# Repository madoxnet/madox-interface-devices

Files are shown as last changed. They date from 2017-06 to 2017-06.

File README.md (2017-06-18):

Madox-Ergonomic-Trackball
Mouse-Ergonomics-Test

|Function|Component|Module|
|---|---|---|
|Processing|ARM Cortex M4F|Adafruit Feather nRF52 Bluefruit LE |
|Power source|1000 mAh Lithium Polymer||
|Optical Sensing|Avago ADNS-9800||
|Optical Lens|Avago ADNS-6190-002||

## Design Parameters
|Parameter|Min|Nom|Max|
|---|---|---|---|
|Sensing distance|2.18mm|2.4mm|2.62|
|Bearing diameter||3mm||
|Trackball diameter||40mm||
|Handedness||Right||

## Controls
- Left Mouse Button
- Right Mouse Button
- Scroll Wheel
- Scroll Wheel Centre Mouse
- Power Switch
- ~~Scroll Wheel left right = Ctrl Tab / Ctrl Shift Tab?~~

## Target Specifications
|Parameter|Min|
|---|---|
|Ball diameter|40mm|
|Ball Material|Tiger's Eye|
|Ball Suspension|3mm Silicon Nitride (Si<sub>3</sub>N<sub>4</sub>) Round Bearings in Polycprolactone casing |
|Construction|Acrylonitrile butadiene styrene|
|Tracking Technology|Laser Optical Sensing|
|Tracking Resolution|Up to 8200 counts per inch|
|Tracking Speed|Up to 150 inches per second|

<https://en.wikipedia.org/wiki/Tiger%27s_eye>
<https://en.wikipedia.org/wiki/Silicon_nitride>

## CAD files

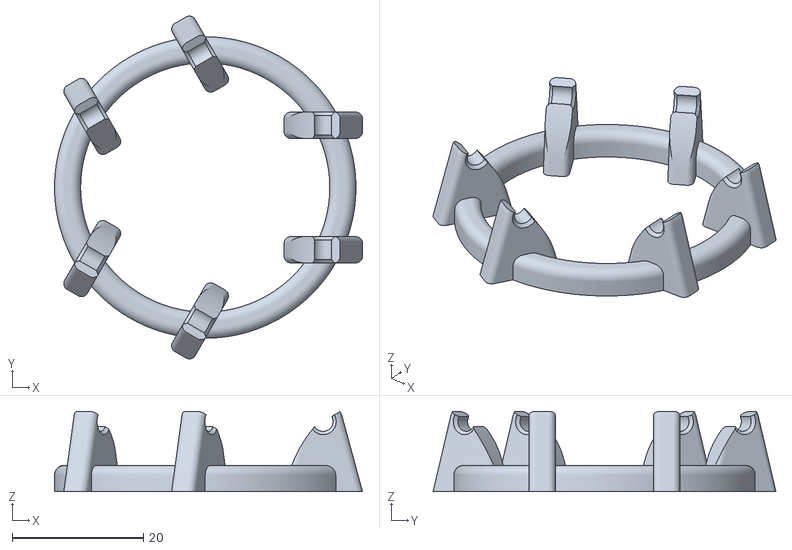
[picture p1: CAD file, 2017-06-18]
hw/test/TrackballTest-Roller.stl
47.0 x 52.3 x 12.2

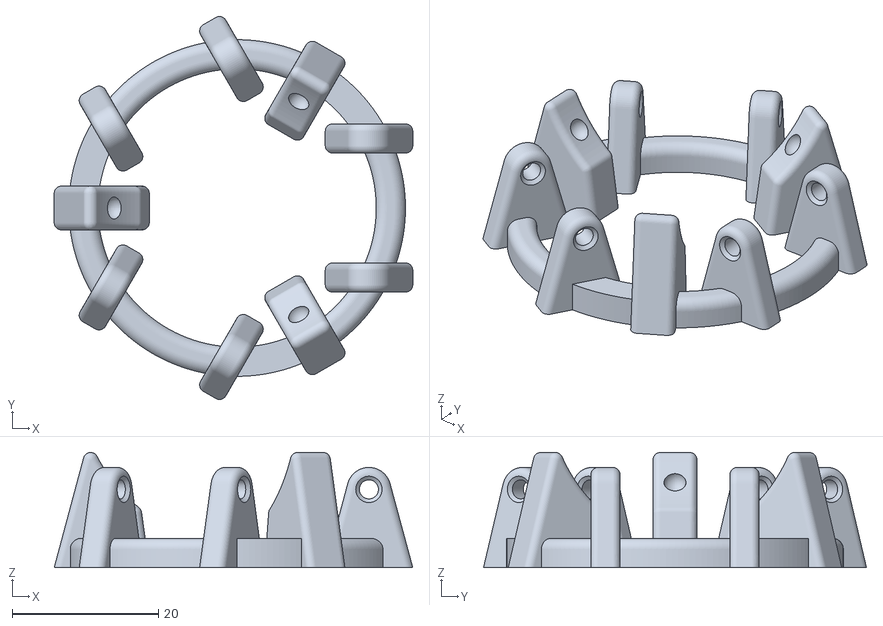
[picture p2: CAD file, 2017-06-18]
hw/test/TrackballTest-Frankenstein.stl
49.0 x 52.3 x 15.7

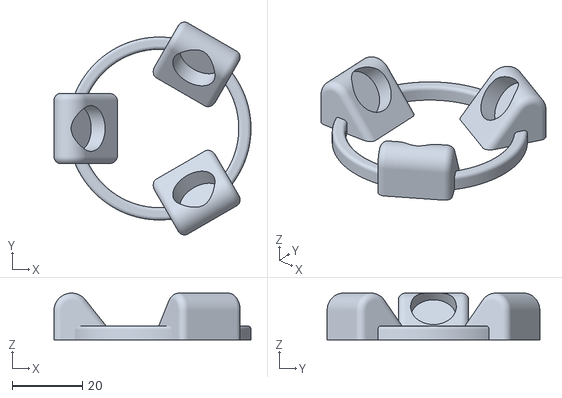
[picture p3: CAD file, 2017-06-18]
hw/test/TrackballTest-BallTransferUnit.stl
56.0 x 60.5 x 13.3

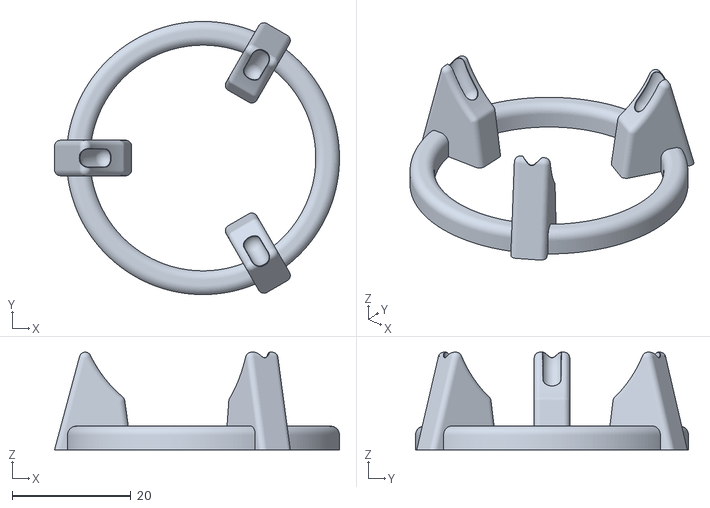
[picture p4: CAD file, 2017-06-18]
hw/test/TrackballTest-Ball.stl
48.0 x 46.0 x 16.5

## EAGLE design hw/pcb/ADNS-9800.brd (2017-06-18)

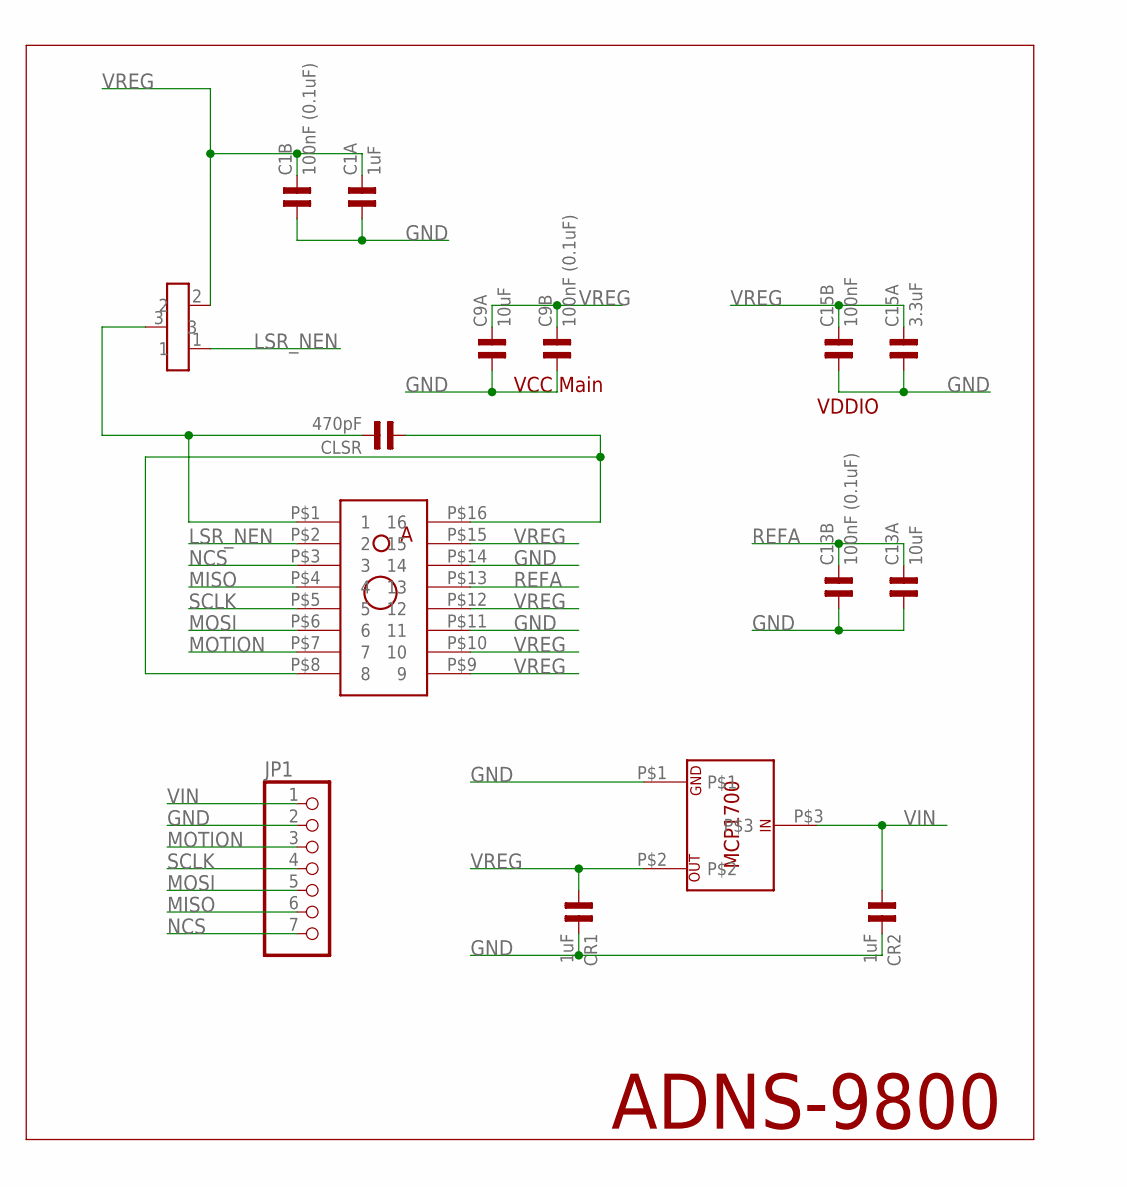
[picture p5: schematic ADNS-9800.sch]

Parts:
C1A: 1uF; 0603
C1B, C9B, C13B: 100nF (0.1uF); 0603
C9A, C13A: 10uF; 0603
C15A: 3.3uF; 0603
C15B: 100nF; 0603
CLSR: 470pF; 0603
CR1, CR2: 1uF; 0603
JP1: PINHD-1X7; 1X07
Q1: TRANSISTOR_SC-75; SC-75_TRANSISTOR
U$1: AVAGO_ADNS-9500
U$2: MCP1700__LDO

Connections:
CM: CLSR.2, Q1.3, U$1.P$1 (1)
GND: C1A.1, C1B.1, C9A.1, C9B.1, C13A.1, C13B.1, C15A.1, C15B.1, CR1.2, CR2.2, JP1.2, U$1.P$11 (11), U$1.P$14 (14), U$2.P$1
LSR_NEN: Q1.1, U$1.P$2 (2)
MISO: JP1.6, U$1.P$4 (4)
MOSI: JP1.5, U$1.P$6 (6)
MOTION: JP1.3, U$1.P$7 (7)
unnamed: CLSR.1, U$1.P$8 (8), U$1.P$16 (16)
NCS: JP1.7, U$1.P$3 (3)
REFA: C13A.2, C13B.2, U$1.P$13 (13)
SCLK: JP1.4, U$1.P$5 (5)
VIN: CR2.1, JP1.1, U$2.P$3
VREG: C1A.2, C1B.2, C9A.2, C9B.2, C15A.2, C15B.2, CR1.1, Q1.2, U$1.P$9 (9), U$1.P$10 (10), U$1.P$12 (12), U$1.P$15 (15), U$2.P$2

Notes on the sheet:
ADNS-9800
VDDIO
VCC Main

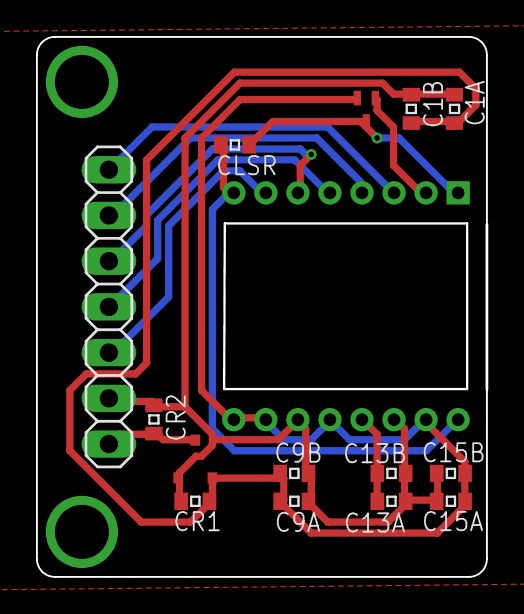
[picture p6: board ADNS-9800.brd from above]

Board: 2 copper layers, 25.0 x 30.0 mm, 15 parts (0 on the bottom side), 12 nets.

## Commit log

2017-06-18 Initial Commit
    PCB and Test STL files
    [ADNS-9800.brd, ADNS-9800.sch, TrackballTest-Ball.stl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]
2017-06-22 Initial Gerbers
